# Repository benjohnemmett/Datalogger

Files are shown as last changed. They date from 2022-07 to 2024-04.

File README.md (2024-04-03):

# Datalogger
ATMega328-based custom data logger hardware &amp; firmware files. Currently, this project reads location data from a GPS module and writes it to a .csv file on an SD card. It is designed to work with a BN-220 GPS module.

Details of design, testing, and issues can be found here https://notes.benjemmett.com/archives/375

## Warning!
This project is in a rough draft state and currently includes significant hardware design issues.

- Incorrect exposed pad connection in 5v linear regulator
- GPS connector pad order does not match the cable provided with the BN-220 GPS module
- Missing FTDI DTR pin connection for programming with the Arduino bootloader
- Incorrect SD Card detect wiring causes light to always be on

## Log File Format
The log file consists of the BN-220 data written directly to a csv file. It can operate in two modes: 
1. Record only GGA messages
2. Record all messages

The Log File name format consists of a the date and a record number followed by the ".csv" extension. The format is as follows, DDMMYYXX.csv where:
- DD is the day of the month
- MM is month
- YY is the year
- XX is a record number incremented on each startup in the range [0-99]
For example, if the next record number is 42 and the current date is April 20, 2023 and the version number is 00 then the filename would be 20042342.csv

## Indicator Lights
The board includes 5 status LEDs numbered 0 to 4, where LED 0 is closest to the MCU. LED 0 indicates a critical error has occured.

Startup sequence is as follows:
1. Indicate DIP switch position.
  1. If DIP 1 is enabled, LED_3 blinks 3 times
  1. If DIP 2 is enabled, LED_4 blinks 3 times
1. Each LED blinks one time briefly in order from LED_0 to LED_4
1. Slow LED_1 toggling indicates an SD card failure. SD Card initialization is retried every 500ms until successful.
1. Three fast LED_1 blinks indicates successful SD card initialization.
1. LED_2 blinks indicate that GPS is being read and checked for synchronization before continuing.
1. LED_1 & LED_2 simultaneous blinks indicate that GPS data is being read until a valid date and time stamp is found.

During data collection:
- LED_3 is illuminated while reading GPS data
- LED_4 is illuminated while writing data to the SD card
- LED_0 is illuminated if there is an SD card write error

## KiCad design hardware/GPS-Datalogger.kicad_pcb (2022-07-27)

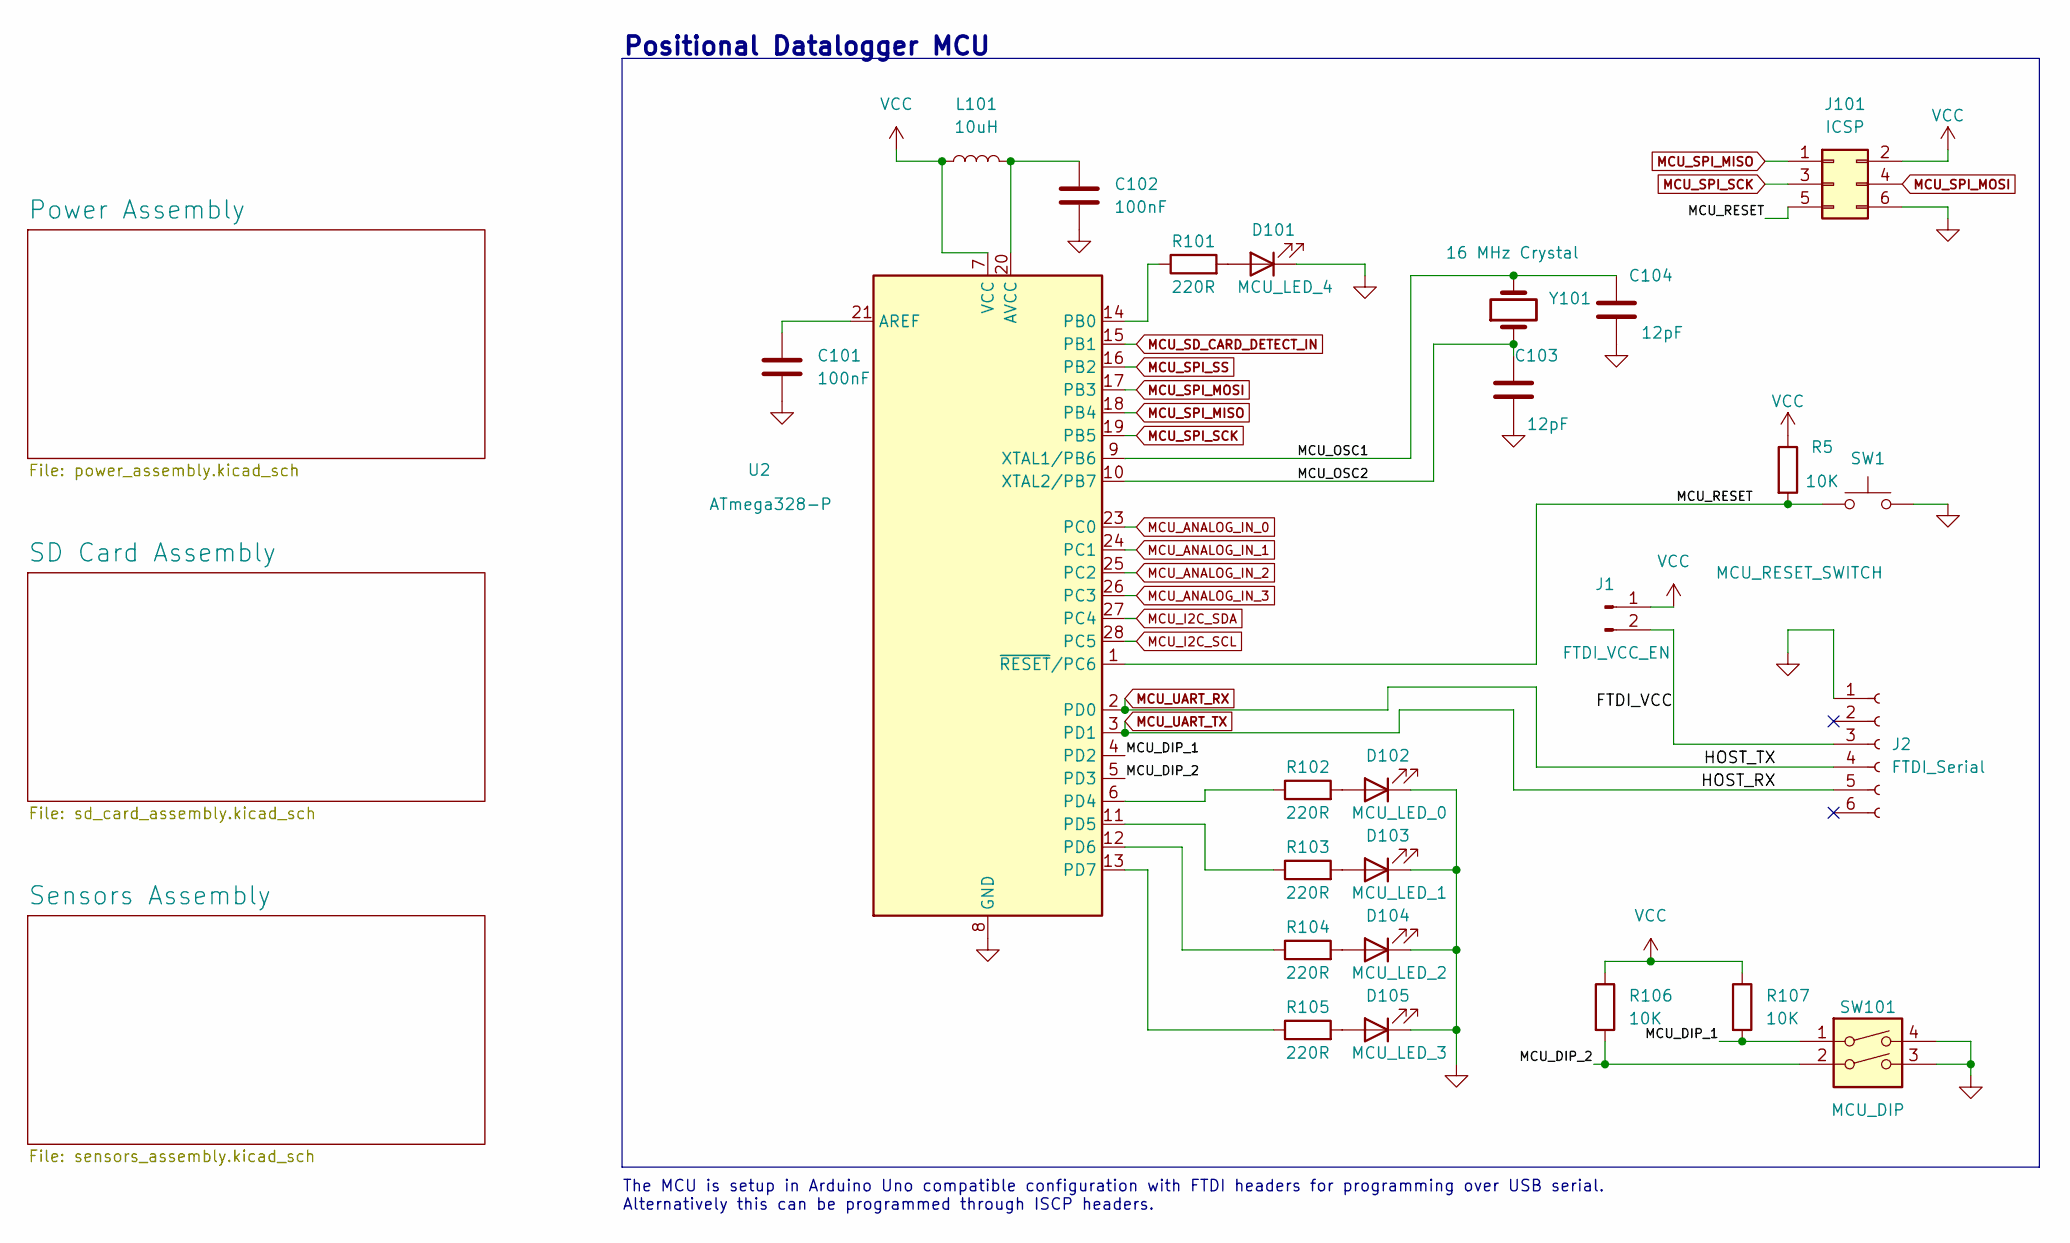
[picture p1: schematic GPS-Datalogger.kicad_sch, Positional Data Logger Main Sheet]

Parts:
C101, C102: 100nF; C_0805_2012Metric_Pad1.18x1.45mm_HandSolder
C103, C104: 12pF; C_0805_2012Metric_Pad1.18x1.45mm_HandSolder
D101: MCU_LED_4; LED_0805_2012Metric_Pad1.15x1.40mm_HandSolder
D102: MCU_LED_0; LED_0805_2012Metric_Pad1.15x1.40mm_HandSolder
D103: MCU_LED_1; LED_0805_2012Metric_Pad1.15x1.40mm_HandSolder
D104: MCU_LED_2; LED_0805_2012Metric_Pad1.15x1.40mm_HandSolder
D105: MCU_LED_3; LED_0805_2012Metric_Pad1.15x1.40mm_HandSolder
J1: FTDI_VCC_EN; PinHeader_1x02_P2.54mm_Vertical
J2: FTDI_Serial; PinSocket_1x06_P2.54mm_Vertical
J101: ICSP; PinHeader_2x03_P2.54mm_Vertical
L101: 10uH; L_Radial_D6.0mm_P4.00mm
R5, R106, R107: 10K; R_0805_2012Metric_Pad1.20x1.40mm_HandSolder
R101, R102, R103, R104, R105: 220R; R_0805_2012Metric_Pad1.20x1.40mm_HandSolder
SW1: MCU_RESET_SWITCH; SW_SPST_FSMSM
SW101: MCU_DIP; SW_DIP_SPSTx02_Slide_Copal_CHS-02B_W7.62mm_P1.27mm
U2: ATmega328-P; DIP-28_W7.62mm
Y101: 16 MHz Crystal; Crystal_HC18-U_Vertical

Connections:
/FTDI_VCC: J1.2, J2.3
/MCU_DIP_1: R107.2, SW101.1, U2.4 (PD2)
/MCU_DIP_2: R106.2, SW101.2, U2.5 (PD3)
/MCU_OSC1: C104.2, U2.9 (XTAL1/PB6), Y101.2
/MCU_OSC2: C103.2, U2.10 (XTAL2/PB7), Y101.1
/MCU_RESET: J101.5, R5.2, SW1.1 (A), U2.1 (~RESET/PC6)
GND: C101.2, C102.2, C103.1, C104.1, D101.1 (K), D102.1 (K), D103.1 (K), D104.1 (K), D105.1 (K), J2.1, J101.6, SW1.2 (B), SW101.3, SW101.4, U2.8 (GND), U2.22 (GND); also elsewhere on the board
MCU_ANALOG_IN_0: U2.23 (PC0); also elsewhere on the board
MCU_ANALOG_IN_1: U2.24 (PC1); also elsewhere on the board
MCU_ANALOG_IN_2: U2.25 (PC2); also elsewhere on the board
MCU_ANALOG_IN_3: U2.26 (PC3); also elsewhere on the board
MCU_I2C_SCL: U2.28 (PC5); also elsewhere on the board
MCU_I2C_SDA: U2.27 (PC4); also elsewhere on the board
MCU_SD_CARD_DETECT_IN: U2.15 (PB1); also elsewhere on the board
MCU_SPI_MISO: J101.1, U2.18 (PB4); also elsewhere on the board
MCU_SPI_MOSI: J101.4, U2.17 (PB3); also elsewhere on the board
MCU_SPI_SCK: J101.3, U2.19 (PB5); also elsewhere on the board
MCU_SPI_SS: U2.16 (PB2); also elsewhere on the board
MCU_UART_RX: J2.4, U2.2 (PD0); also elsewhere on the board
MCU_UART_TX: J2.5, U2.3 (PD1); also elsewhere on the board
unnamed: C101.1, U2.21 (AREF)
unnamed: C102.1, L101.2, U2.20 (AVCC)
unnamed: D101.2 (A), R101.2
unnamed: D102.2 (A), R102.2
unnamed: D103.2 (A), R103.2
unnamed: D104.2 (A), R104.2
unnamed: D105.2 (A), R105.2
unnamed: R101.1, U2.14 (PB0)
unnamed: R102.1, U2.6 (PD4)
unnamed: R103.1, U2.11 (PD5)
unnamed: R104.1, U2.12 (PD6)
unnamed: R105.1, U2.13 (PD7)
VCC: J1.1, J101.2, L101.1, R5.1, R106.1, R107.1, U2.7 (VCC); also elsewhere on the board

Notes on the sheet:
Positional Datalogger MCU
The MCU is setup in Arduino Uno compatible configuration with FTDI headers for programming over USB serial. Alternatively this can be programmed through ISCP headers.

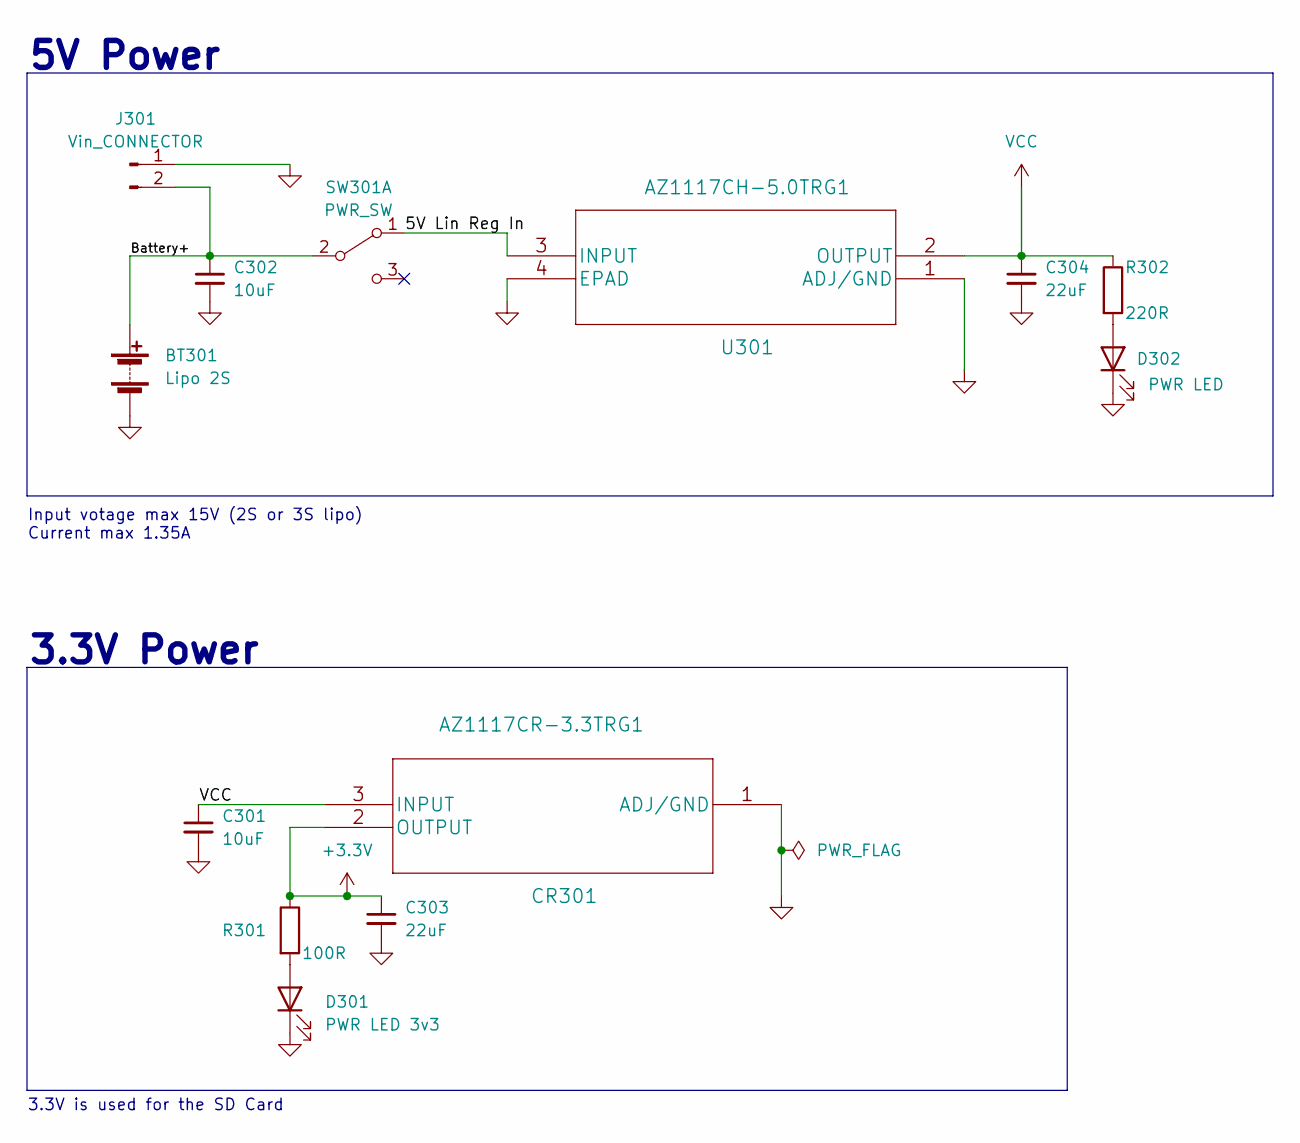
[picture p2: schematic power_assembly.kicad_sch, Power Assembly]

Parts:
BT301: Lipo 2S; AMASS_XT30U-M_1x02_P5.0mm_Vertical
C301, C302: 10uF; CP_Radial_D4.0mm_P1.50mm
C303, C304: 22uF; CP_Radial_D4.0mm_P1.50mm
CR301: AZ1117CR-3.3TRG1
D301: PWR LED 3v3; LED_0805_2012Metric_Pad1.15x1.40mm_HandSolder
D302: PWR LED; LED_0805_2012Metric_Pad1.15x1.40mm_HandSolder
J301: Vin_CONNECTOR; PinHeader_1x02_P2.54mm_Vertical
R301: 100R; R_0805_2012Metric_Pad1.20x1.40mm_HandSolder
R302: 220R; R_0805_2012Metric_Pad1.20x1.40mm_HandSolder
SW301: PWR_SW; SW_DPDT_MSS22D18_6pin_bje
U301: AZ1117CH-5.0TRG1

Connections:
+3V3: C303.1, CR301.2 (OUTPUT), R301.1; also elsewhere on the board
/Power Assembly/5V Lin Reg In: SW301.1 (A), U301.3 (INPUT)
/Power Assembly/Battery+: BT301.2 (+), C302.1, J301.2, SW301.2 (B)
GND: BT301.1 (-), C301.2, C302.2, C303.2, C304.2, CR301.1 (ADJ/GND), D301.1 (K), D302.1 (K), J301.1, U301.1 (ADJ/GND), U301.4 (EPAD); also elsewhere on the board
unnamed: D301.2 (A), R301.2
unnamed: D302.2 (A), R302.2
VCC: C301.1, C304.1, CR301.3 (INPUT), R302.1, U301.2 (OUTPUT); also elsewhere on the board

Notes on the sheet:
3.3V is used for the SD Card
3.3V Power
Input votage max 15V (2S or 3S lipo) Current max 1.35A
5V Power

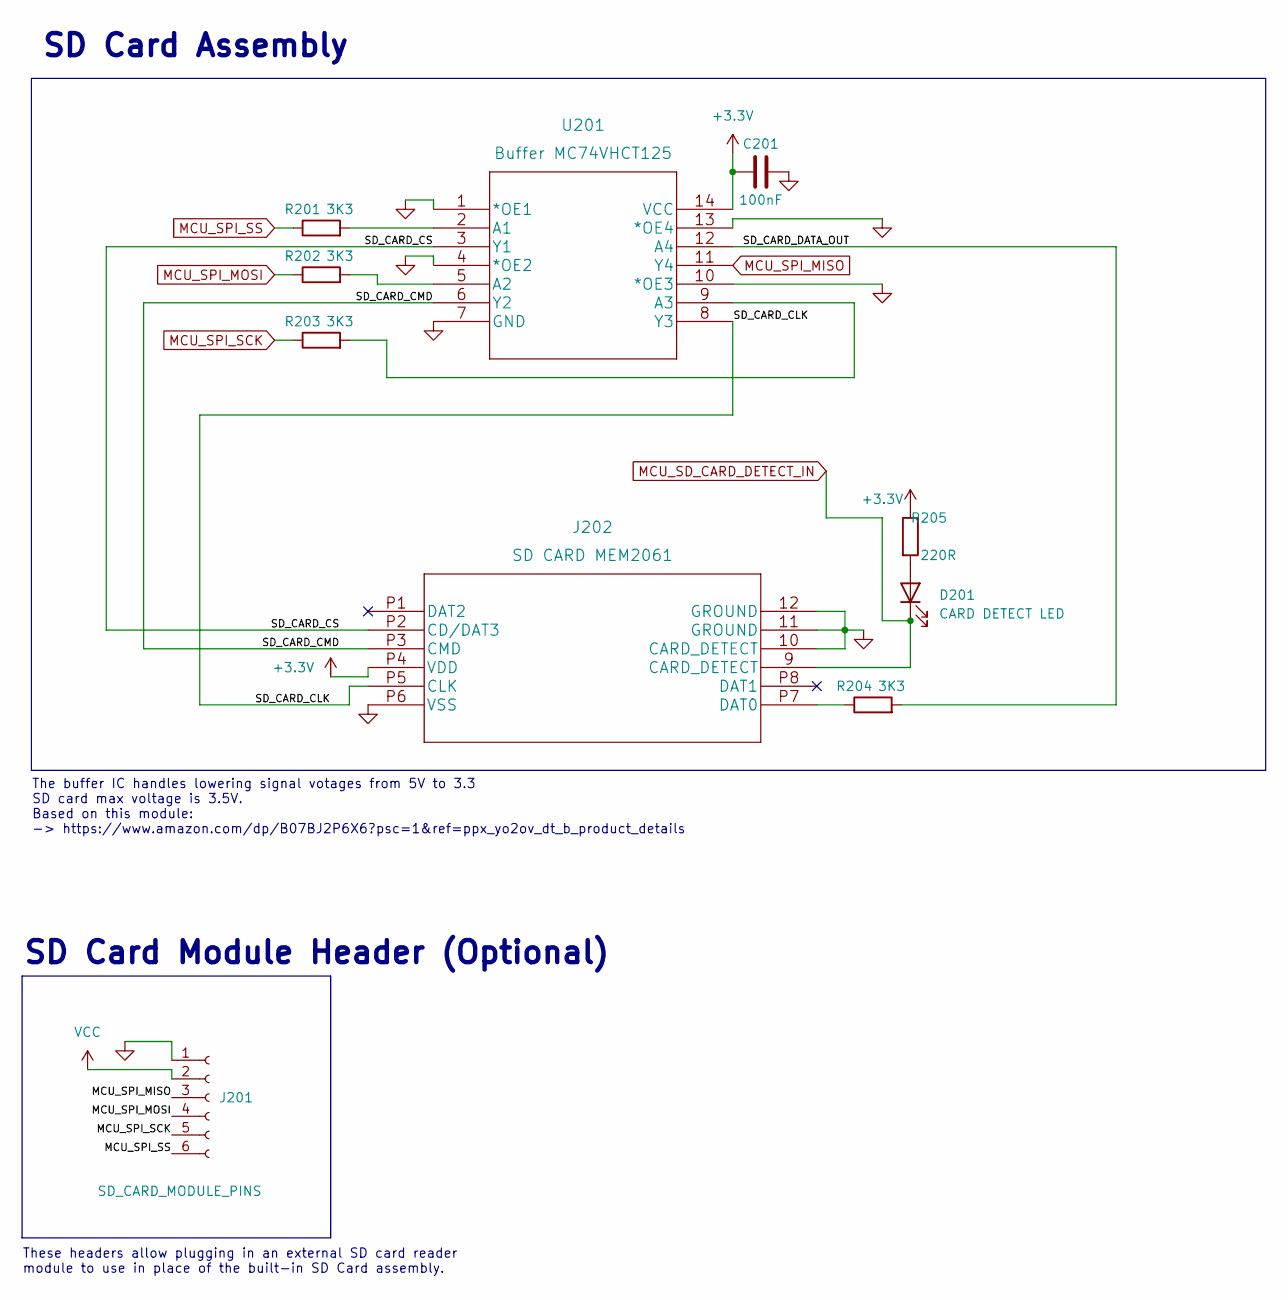
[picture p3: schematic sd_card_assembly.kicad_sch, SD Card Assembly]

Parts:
C201: 100nF; C_0805_2012Metric_Pad1.18x1.45mm_HandSolder
D201: CARD DETECT LED; LED_0805_2012Metric_Pad1.15x1.40mm_HandSolder
J201: SD_CARD_MODULE_PINS; PinSocket_1x06_P2.54mm_Vertical
J202: SD CARD MEM2061; MEM2061
R201, R202, R203, R204: 3K3; R_0805_2012Metric_Pad1.20x1.40mm_HandSolder
R205: 220R; R_0805_2012Metric_Pad1.20x1.40mm_HandSolder
U201: Buffer MC74VHCT125; MC74VHCT125ADR2G

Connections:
+3V3: C201.1, J202.P4 (VDD), R205.1, U201.14 (VCC); also elsewhere on the board
/SD Card Assembly/SD_CARD_CLK: J202.P5 (CLK), U201.8 (Y3)
/SD Card Assembly/SD_CARD_CMD: J202.P3 (CMD), U201.6 (Y2)
/SD Card Assembly/SD_CARD_CS: J202.P2 (CD/DAT3), U201.3 (Y1)
/SD Card Assembly/SD_CARD_DATA_OUT: R204.2, U201.12 (A4)
GND: C201.2, J201.1, J202.10 (CARD_DETECT), J202.11 (GROUND), J202.12 (GROUND), J202.P6 (VSS), U201.1 (*OE1), U201.4 (*OE2), U201.7 (GND), U201.10 (*OE3), U201.13 (*OE4); also elsewhere on the board
MCU_SD_CARD_DETECT_IN: D201.1 (K), J202.9 (CARD_DETECT); also elsewhere on the board
MCU_SPI_MISO: J201.3, U201.11 (Y4); also elsewhere on the board
MCU_SPI_MOSI: J201.4, R202.1; also elsewhere on the board
MCU_SPI_SCK: J201.5, R203.1; also elsewhere on the board
MCU_SPI_SS: J201.6, R201.1; also elsewhere on the board
unnamed: D201.2 (A), R205.2
unnamed: J202.P7 (DAT0), R204.1
unnamed: R201.2, U201.2 (A1)
unnamed: R202.2, U201.5 (A2)
unnamed: R203.2, U201.9 (A3)
VCC: J201.2; also elsewhere on the board

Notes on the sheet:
The buffer IC handles lowering signal votages from 5V to 3.3 SD card max voltage is 3.5V. Based on this module: -> https://www.amazon.com/dp/B07BJ2P6X6?psc=1&ref=ppx_yo2ov_dt_b_product_details
SD Card Module Header (Optional)
SD Card Assembly
These headers allow plugging in an external SD card reader module to use in place of the built-in SD Card assembly.

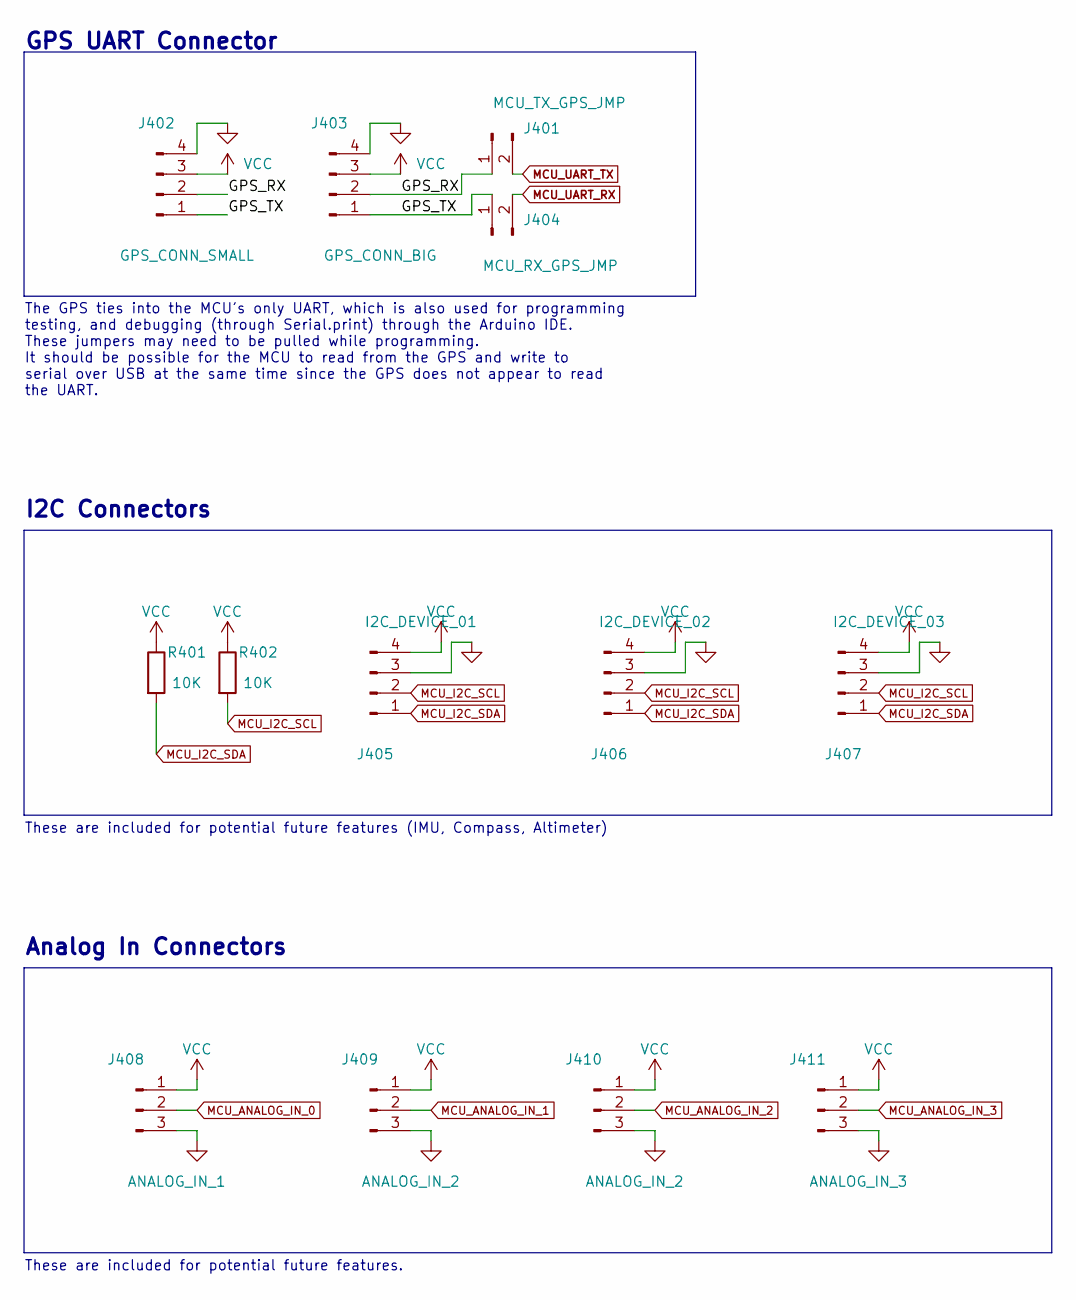
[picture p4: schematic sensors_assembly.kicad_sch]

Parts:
J401: MCU_TX_GPS_JMP; PinSocket_1x02_P2.54mm_Vertical
J402: GPS_CONN_SMALL; CONN_BM04B-SRSS-TB(LF)(SN)
J403: GPS_CONN_BIG; PinSocket_1x04_P2.54mm_Vertical
J404: MCU_RX_GPS_JMP; PinSocket_1x02_P2.54mm_Vertical
J405: I2C_DEVICE_01; JST_PH_B4B-PH-K_1x04_P2.00mm_Vertical
J406: I2C_DEVICE_02; JST_PH_B4B-PH-K_1x04_P2.00mm_Vertical
J407: I2C_DEVICE_03; JST_PH_B4B-PH-K_1x04_P2.00mm_Vertical
J408: ANALOG_IN_1; JST_PH_B3B-PH-K_1x03_P2.00mm_Vertical
J409, J410: ANALOG_IN_2; JST_PH_B3B-PH-K_1x03_P2.00mm_Vertical
J411: ANALOG_IN_3; JST_PH_B3B-PH-K_1x03_P2.00mm_Vertical
R401, R402: 10K; R_0805_2012Metric_Pad1.20x1.40mm_HandSolder

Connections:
/Sensors Assembly/GPS_RX: J401.1, J402.2, J403.2
/Sensors Assembly/GPS_TX: J402.1, J403.1, J404.1
GND: J402.4, J403.4, J405.3, J406.3, J407.3, J408.3, J409.3, J410.3, J411.3; also elsewhere on the board
MCU_ANALOG_IN_0: J408.2; also elsewhere on the board
MCU_ANALOG_IN_1: J409.2; also elsewhere on the board
MCU_ANALOG_IN_2: J410.2; also elsewhere on the board
MCU_ANALOG_IN_3: J411.2; also elsewhere on the board
MCU_I2C_SCL: J405.2, J406.2, J407.2, R402.2; also elsewhere on the board
MCU_I2C_SDA: J405.1, J406.1, J407.1, R401.2; also elsewhere on the board
MCU_UART_RX: J404.2; also elsewhere on the board
MCU_UART_TX: J401.2; also elsewhere on the board
VCC: J402.3, J403.3, J405.4, J406.4, J407.4, J408.1, J409.1, J410.1, J411.1, R401.1, R402.1; also elsewhere on the board

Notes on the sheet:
The GPS ties into the MCU's only UART, which is also used for programming testing, and debugging (through Serial.print) through the Arduino IDE. These jumpers may need to be pulled while programming. It should be possible for the MCU to read from the GPS and write to serial over USB at the same tim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
These are included for potential future features (IMU, Compass, Altimeter)
GPS UART Connector
These are included for potential future features.
Analog In Connectors
I2C Connectors

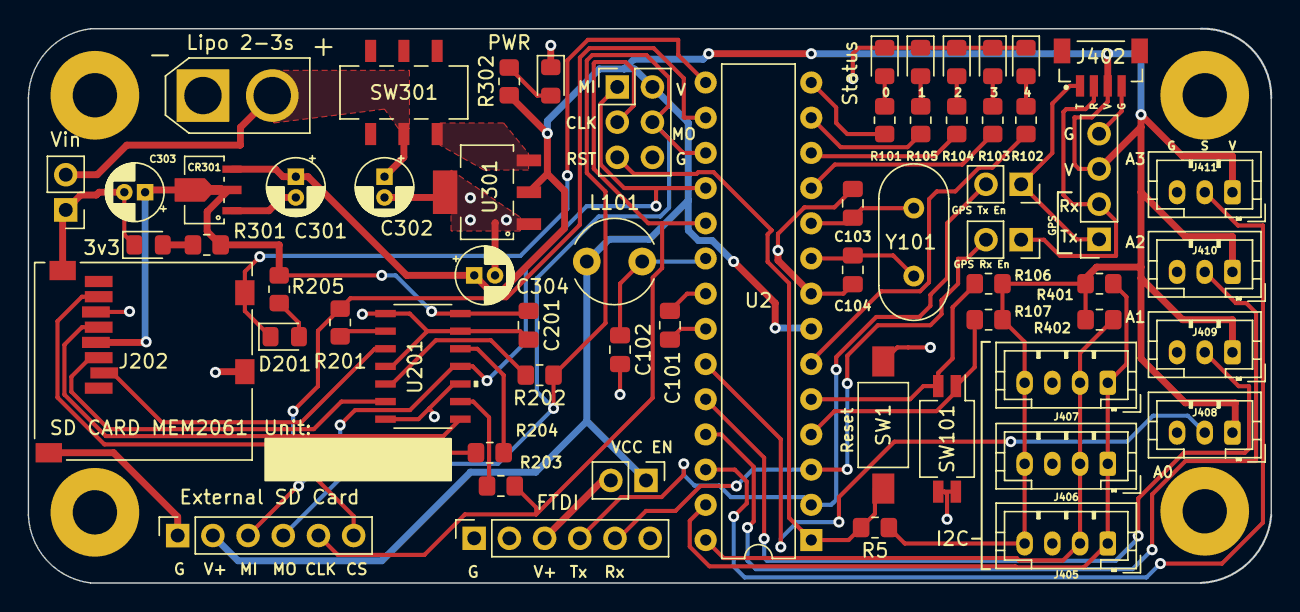
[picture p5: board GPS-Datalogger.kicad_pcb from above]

Board: 2 copper layers, 89.7 x 40.0 mm, 65 parts (0 on the bottom side), 49 nets.

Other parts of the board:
TH0, TH1, TH3: MountingHole_3.2mm_M3_Pad
TH2: (no value)

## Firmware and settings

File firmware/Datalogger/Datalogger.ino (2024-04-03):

/*
  This sketch reads data from a GPS module over UART and writes it to a file on an SD card

   SD card attached to SPI bus:
   ** MOSI - pin 11
   ** MISO - pin 12
   ** CLK - pin 13
   ** CS - pin 10 (PB2)

   DIP SWITCHES
   ** DIP1 - PD2 - Arduino pin 2
   ** DIP2 - PD3 - Arduino pin 3

   Arduino IDE Using USBasp programmer
    - Arduino
        - Board -> Arduino Uno
        - Port -> None
        - Programmer -> USBasp
    - Sketch -> Upload using programmer
        - Cmd + Shift + U
*/

#include <EEPROM.h>
#include <SPI.h>
#include <SD.h>
#include "GpsUtils.h"
#include "StatusLights.h"

#define CHIP_SELECT_PIN 10
#define CARD_DETECT_IN 9
#define EEPROM_ADDR_RECORD_NUMBER 0
#define MAX_RECORD_NUMBER 100

#define DIP_1 3
#define DIP_2 2

enum WriteMode { WRITE_ALL, ONLY_GGA };

String file_name = "no_name.csv";
String file_extension = "csv";
uint8_t record_number;
File myFile;
WriteMode write_mode = ONLY_GGA;

void setup() {
  Serial.begin(9600);
  setup_status_lights();

  uint8_t last_record_number = EEPROM.read(EEPROM_ADDR_RECORD_NUMBER);
  record_number = (last_record_number + 1) % MAX_RECORD_NUMBER;
  EEPROM.write(EEPROM_ADDR_RECORD_NUMBER, record_number);
  Serial.print("Beginning record number ");
  Serial.println(record_number);
  
  pinMode(CHIP_SELECT_PIN, OUTPUT);
  
  if (getDipOneValue()) {
    Serial.println("write_mode = WRITE_ALL");
    fast_blinks(STATUS_LED_3, 3);
    write_mode = WRITE_ALL;
  }

  if (getDipTwoValue()) {
    fast_blinks(STATUS_LED_4, 3);
  }

  start_up_lights();
  delay(500);

  bool card_mounted = false;
  while(!card_mounted) {
    Serial.println("Initializing SD card...");
    if (!SD.begin(CHIP_SELECT_PIN)) {
      digitalWrite(STATUS_LED_1, HIGH);
      Serial.println("initialization failed!");
      
      delay(500);
      digitalWrite(STATUS_LED_1, LOW);
    } else {
      card_mounted = true;
    }
  }
  
  fast_blinks(STATUS_LED_1, 3);
  delay(500);
  Serial.println("initialization done.");

  if (write_mode == ONLY_GGA) {
    Serial.println("Getting GPS data..");
    uint8_t status_toggle = 1;
    String data_string = Serial.readStringUntil('\n');
    while(!gpsIsSynchronized(data_string)) {
      data_string = Serial.readStringUntil('\n');
      digitalWrite(STATUS_LED_2, status_toggle);
      status_toggle = !status_toggle;
    }
  
    data_string = Serial.readStringUntil('\n');
    while (!stringIsRmcData(data_string)) {
      data_string = Serial.readStringUntil('\n');
      digitalWrite(STATUS_LED_1, status_toggle); // Blink LED 1 & 2 until date & time are found
      digitalWrite(STATUS_LED_2, status_toggle);
      status_toggle = !status_toggle;
    }
    
    // There is an 8 char filename limit DDMMYYXX.cVV
    // https://forum.arduino.cc/t/sd-card-filename-issue/491760/4
    // VV is the version number
    String date_time_string = getDateFromRmcString(data_string);
    file_name = date_time_string + getRecordNumberAsString() + "." + file_extension;
  }
  else {
    file_name = "data_" + getRecordNumberAsString() + "." + file_extension;
  }
  Serial.print("Using filename ");
  Serial.println(file_name);
  
  digitalWrite(STATUS_LED_1, 0);
  digitalWrite(STATUS_LED_2, 0);
  delay(500);
}

void loop() {
  String data_string = Serial.readStringUntil('\n');
  digitalWrite(STATUS_LED_0, 0);
  digitalWrite(STATUS_LED_3, 1);

  switch (write_mode) {
    case WRITE_ALL:
      writeDataToCard(data_string);
      break;
    case ONLY_GGA:
      if (stringIsGgaData(data_string)) {
        writeDataToCard(data_string);
      }
      break;
  }

  digitalWrite(STATUS_LED_3, 0);
  delay(10);
}

void writeDataToCard(String data_string) {
  myFile = SD.open(file_name, FILE_WRITE);
  if (myFile) {
    if (data_string.length() > 0) {
      digitalWrite(STATUS_LED_4, 1);
      myFile.print(data_string);
      digitalWrite(STATUS_LED_4, 0);
    }
    myFile.close();
  } else {
    digitalWrite(STATUS_LED_0, 1);
  }
}

String getRecordNumberAsString() {
  String record_string = String(record_number);
  if (record_number < 10) {
    record_string = "0" + record_string;
  }
  return record_string;
}

uint8_t getDipOneValue() {
  return !digitalRead(DIP_1);
}

uint8_t getDipTwoValue() {
  return !digitalRead(DIP_2);
}

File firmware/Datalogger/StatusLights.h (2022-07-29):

#include <Arduino.h>

#define STATUS_LED_0 8
#define STATUS_LED_1 7
#define STATUS_LED_2 6
#define STATUS_LED_3 5
#define STATUS_LED_4 4

void setup_status_lights() {
  pinMode(STATUS_LED_0, OUTPUT);
  pinMode(STATUS_LED_1, OUTPUT);
  pinMode(STATUS_LED_2, OUTPUT);
  pinMode(STATUS_LED_3, OUTPUT);
  pinMode(STATUS_LED_4, OUTPUT);
}

void fast_blinks(uint8_t light, uint8_t count) {
  for (int i = 0; i < count; i++ ){
    digitalWrite(light, HIGH);
    delay(100);
    digitalWrite(light, LOW);
    delay(200);
  }
}

void slow_blinks(uint8_t light, uint8_t count) {
  for (int i = 0; i < count; i++ ){
    digitalWrite(light, HIGH);
    delay(500);
    digitalWrite(light, LOW);
    delay(250);
  }
}

void start_up_lights() {
  digitalWrite(STATUS_LED_0, HIGH);
  delay(200);
  digitalWrite(STATUS_LED_0, LOW);
  delay(10);
  digitalWrite(STATUS_LED_1, HIGH);
  delay(200);
  digitalWrite(STATUS_LED_1, LOW);
  delay(10);
  digitalWrite(STATUS_LED_2, HIGH);
  delay(200);
  digitalWrite(STATUS_LED_2, LOW);
  delay(10);
  digitalWrite(STATUS_LED_3, HIGH);
  delay(200);
  digitalWrite(STATUS_LED_3, LOW);
  delay(10);
  digitalWrite(STATUS_LED_4, HIGH);
  delay(200);
  digitalWrite(STATUS_LED_4, LOW);
  delay(10);
}

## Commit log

2022-07-27 Initial commit with hardware files.
    [GPS-Datalogger.kicad_pcb, GPS-Datalogger.kicad_sch, power_assembly.kicad_sch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]
2023-04-27 WIP: Partially tested. On hold due to hardware issues. Asserting DIP enabls all serial data to be written to the SD card.
    [Datalogger.ino]
2024-04-03 DIP switch 1 activate WRITE_ALL mode.

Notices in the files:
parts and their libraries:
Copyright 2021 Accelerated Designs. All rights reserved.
